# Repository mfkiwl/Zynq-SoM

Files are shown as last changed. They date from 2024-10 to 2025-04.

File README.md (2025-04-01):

# Zynq SoM Board

## Overview
This repository contains the hardware design files for a System on Module based on Xilinx Zynq 7020 SoC (FPGA + Dual Core ARM Cortex A9).

<!-- ![](img/zynq_pcb_render_test.png) -->
<!-- ![](img/pcb2blender_test_dark.png) -->
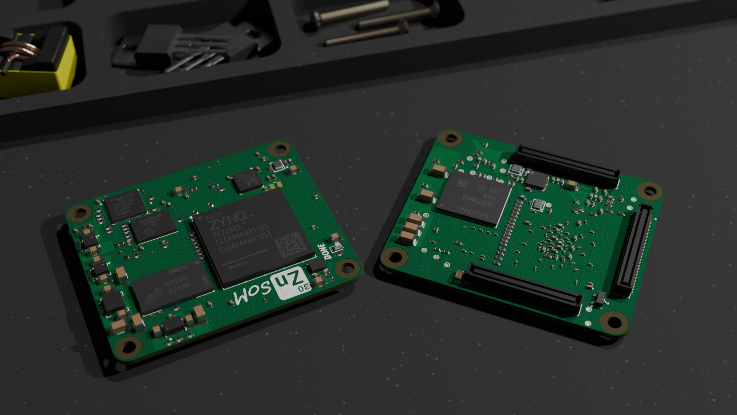
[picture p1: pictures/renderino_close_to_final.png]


## Description

> [!Warning] 
> First prototype is under testing. The design has not been fully verified.

#### Block Diagram

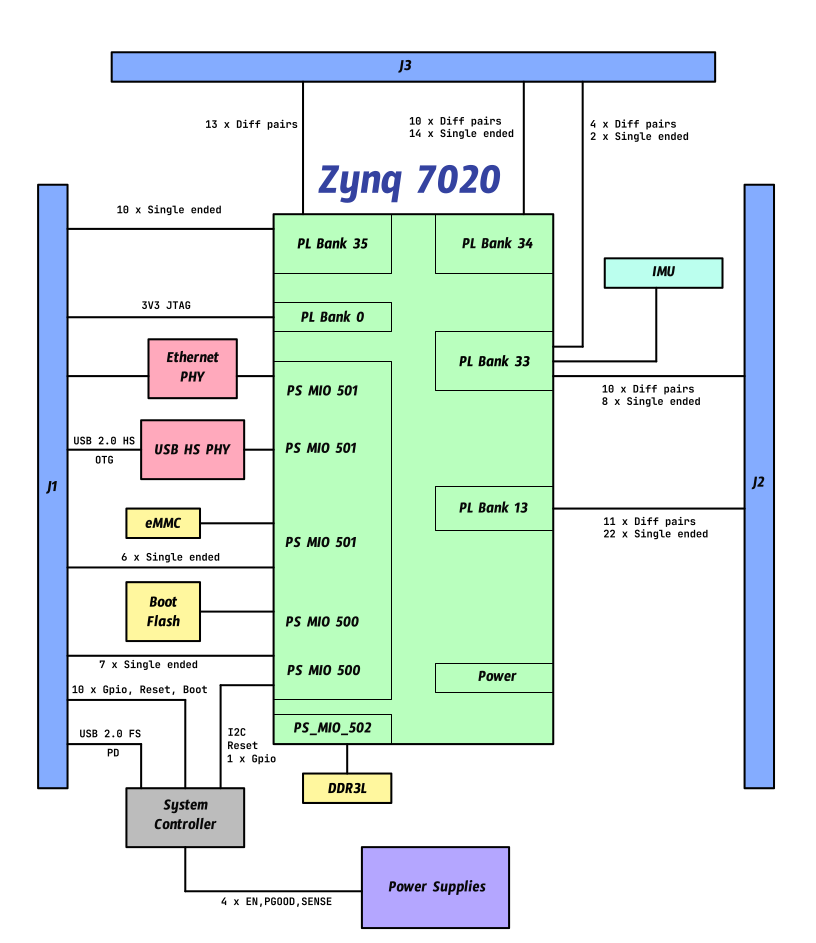
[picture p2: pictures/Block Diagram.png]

##  Features

Memory

- 512Mb DDR3L RAM
- 8Gb eMMC
- 16Mb Boot Flash

Connectivity

- 1x **Ethernet Gigabit**
- 1x **USB 2.0 High Speed** OTG 
- 1x **USB 2.0 Full speed** + USB PD (STM32)

- 7x Zynq PS GPIO (3.3V)
- 6x Zynq PS GPIO (1.8V) (External SD Card)
- 48x Zynq PL differential pairs (1.2-3.3V)
- 56x Zynq PL single ended IO (1.2-3.3V)
- 8x STM32 GPIO (3.3V)

Debug

- Zynq JTAG (3.3V)
- STM32 SWD (3.3V)

## Folder Structure

The repository is structured as follows:
- `schematics` contains the Kicad schematic sheets and schematic pdf 
- `scripts` contains a collection of python scripts used during the SoM/Carrier design phase
- `manufacturing/assembly` containts the BOM and pick-and-place position files
- `manufacturing/fabrication` containts the Gerber files and fabrication pdf 
- `lib` contains footprints and 3d models

## Production

JLCPCB ordering information:

- Layers: 8
- PCB Thickness: 1.2 mm
- Material Type: FR-4 TG155
- Stackup:  JLC08121H-1080A
- Outer Copper Weigth:  1 oz
- Inner Copper Weigth: 0.5 oz
- Minimum via diameter/hole-size: 0.3/0.2 mm
- Via Covering: Epoxy Filled and Capped
- Surface finish: ENIG

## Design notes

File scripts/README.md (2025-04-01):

# Scripts

This  folder contains:
- A python script to add die lengths to the Xilinx SoC footprint
- A python script to calculate SoM pcb track propagation delays
- A Kicad plugin to create a carrier pcb template
- A bash script to generate carrier connector symbols

## Requirements
python pandas

## `footprint_add_die_lengths.py`

This script adds die lengths to the Zynq SoC `<footprint_name>.kicad_mod` footprint.

Xilinx provides Die-to-Package delay data by specifying **max** and **min** delay values (in *ps*). Unluckly, Kicad footprints can only store die-length values (in *mm*).

Equivalent Die-length values are calculated as the average Die-to-Package delay multiplied by the microstrip propagation speed (approximated to 1/6 *mm/ps* for common FR4 boards).

$$ \frac{T_{D,max} + T_{D,min}}{2}\cdot V_{p*}$$

Where:
- $V_{p*}$ = miscrostrip propagation speed (hardcoded to 1/6 *mm/ps*)
- $T_{D}$ = Die-to-Package delay (*ps*)

### Usage
Run in terminal 
```bash
python footprint_add_die_lengths.py xc7z020clg484_delays.csv CLG484_XIL.kicad_mod
```
The resulting footprint is saved as `<footprint_name>_with_die_lengths.kicad_mod`

## `calculate_track_delays.py`
This script calculates propagation delays/skews for the following signal groups:
- DDR CMD/ADDR Bus
- DDR Data lanes
- Boot flash QSPI 
- eMMC SDIO 
- ETH RMGII TX
- ETH RMGII RX
- USB ULPI

Delays are calculated as 

$$ \frac{DL}{V_{p*}} + \sum_{layers} \frac{TL_{\,layer}}{V_{p,layer}}$$

Where:
- $DL$ = Package Die-Length [*mm*] (stored in footprint)
- $V_{p*}$ = 1/6 *mm/ps* (used during Die-Length calculation see [footprint_add_die_lengths](#footprint_add_die_lengthspy))
- $TL_{\,layer}$ = signal trace length for that specific layer [*mm*]
- $V_{p,layer}$ = signal propagation speed for that specific layer and signal type (differential or single-ended) [*mm/ps*]

>[!NOTE]
>- Outer layer Propagation speeds (microstrip) are lower compared to inner layers (stripline).
>- Propagation speed can vary between differential and single-ended signals

Via delays are not considered in the calculations. 

### Usage
1. With pcbnew create a Net Inspector Report named `tracklengths.csv` and save it inside `/scripts` subfolder
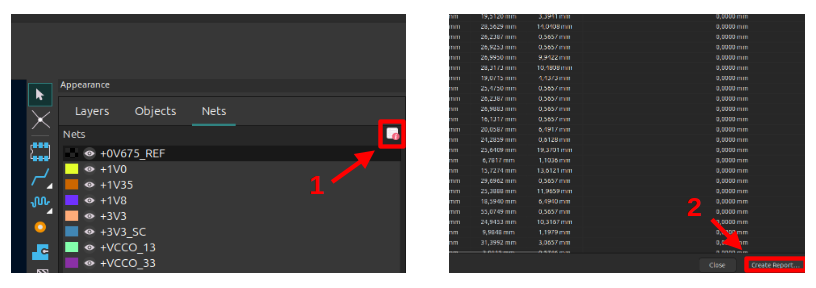
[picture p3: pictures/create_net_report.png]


2. Run in terminal:
```bash
python calculate_track_delays.py tracklengths.csv
```
Results are printed out in terminal.

## `create_carrier_template_plugin.py` 

This script generates a `.kicad_pcb` template used as a starting point for carrier board designs.

It places footprints for
- mating connectors (with die-lengths*)
- standoffs
- testing probes

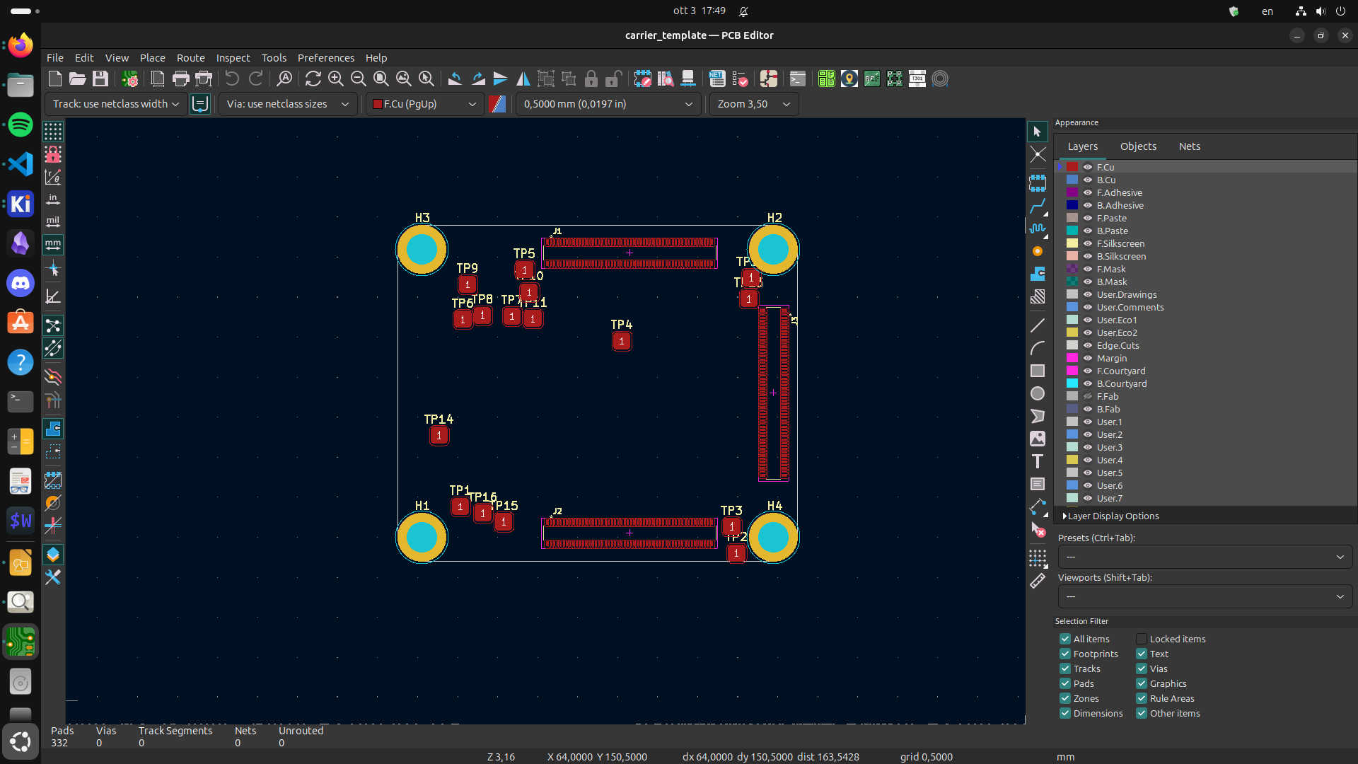
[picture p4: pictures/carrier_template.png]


### Usage
This script needs to be executed inside pcbnew Python scripting console by running:
```python
import os
exec(open(os.path.expandvars("${KIPRJMOD}/scripts/create_carrier_template_plugin.py")).read())
```
The `.kicad_pcb` template file can be found inside the `carrier_template` folder, together with the `.csv` files that will be used by [symbol_creation.bash](#symbol_creationbash) to create the SoM carrier connector symbols.

>[!NOTE]
>Schematic symbols need to be manually linked to the  generated footprints:
>- symbol references needs to be edited to match the  respective `.kicad_pcb` footprint references
>- symbol footprints needs to match the `.kicad_pcb` footprints
## `symbol_creation.bash`

This bash script uses the previously generated `.csv` files to create a  symbol library (`.lib`) containing the SoM carrier  connector symbols.
### Usage
Run in terminal:
```bash
source symbol_creation.bash
```
The library file is saved as `symbol_Zynq_SoM.lib` (Kicad < V6.0). Conversion to the newer `.kicad_sym` format can be done during import by clicking the "Migrate Library" button inside Symbol Library Manager.

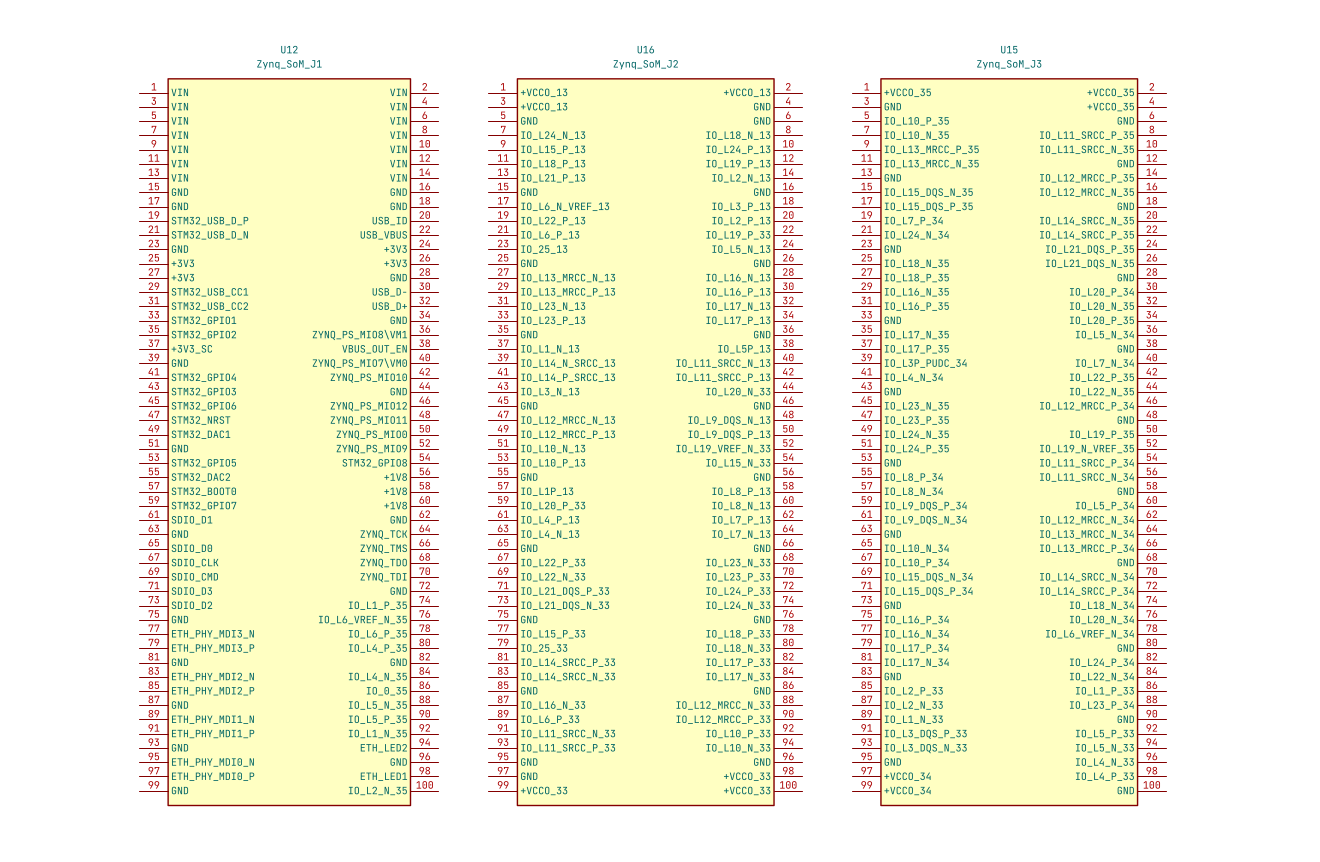
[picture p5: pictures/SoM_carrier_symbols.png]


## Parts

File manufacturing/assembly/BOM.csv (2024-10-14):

Reference | Value | Footprint | Qty | LCSC Part | Digikey
C1,C7,C8,C9,C10,C11,C12,C15,C32,C34,C36,C38,C40,C44,C45,C52,C57,C59,C66,C70,C71,C77,C78,C79,C87,C88,C95,C97,C103,C123,C128,C129,C139,C141 | 4u7 | Capacitor_SMD:C_0402_1005Metric | 34 | C368809
C2,C3,C4,C5,C6,C16,C17,C18,C19,C20,C21,C22,C138,C142 | 100n | Capacitor_SMD:C_0402_1005Metric | 14 | gia
C13,C23,C33,C35,C37,C39,C41,C43,C46,C47,C48,C50,C53,C54,C55,C56,C61,C62,C67,C69,C72,C76,C80,C81,C82,C83,C84,C85,C89,C90,C91,C92,C94,C98,C99,C100,C101,C102,C107,C108,C112,C114,C130,C131,C132,C133,C134,C135,C136,C137 | 470n | Capacitor_SMD:C_0201_0603Metric | 50 | C85926
C14 | 100n | Capacitor_SMD:C_0402_1005Metric | 1 | -
C24,C27,C28,C29,C31,C49,C73,C74,C75,C86,C127 | 47u | Capacitor_SMD:C_0805_2012Metric | 11 | C16780
C25,C26,C30 | 22u | Capacitor_SMD:C_0805_2012Metric | 3 | C98190
C42,C51,C58,C60,C63,C64,C68,C93,C96 | 100u | Capacitor_SMD:C_1206_3216Metric | 9 | C15008
C65 | 10u | Capacitor_SMD:C_0402_1005Metric | 1 | C15525////
C104,C105,C106,C109,C110,C111,C113,C118,C119,C120,C121,C122,C124,C125,C126 | 47n | Capacitor_SMD:C_0201_0603Metric | 15 | C85925
D2 | LED_Small | LED_SMD:LED_0603_1608Metric | 1 | -
H1,H2,H3,H4 | MountingHole | Mylibrary:MountingHole_2.7mm_M2.5_ISO14580_MOD | 4 | -
J1,J2,J3 | DF40C-100DS-0.4V_51 | Mylibrary:HRS_DF40C-100DS-0.4V_51_ | 3 |  | DF40HC(3.0)-100DS-0.4V(51)
L1 | 3u3 | Mylibrary:L_0806_2.0x1.6mm | 1 | C98336
L2,L3,L4,L6,L7,L8,L9 | 120R | Inductor_SMD:L_0402_1005Metric | 7 | C275478
L5 | 600@100MHz | Inductor_SMD:L_0402_1005Metric | 1 | C337875/gia
Q3 | NMOS | Package_TO_SOT_SMD:SOT-23 | 1
R1,R5,R6,R13,R15,R39,R40,R41,R42,R43,R44,R74,R75,R76,R77,R86,R87,R88,R89,R90,R92,R93,R94,R97,R100 | 10k | Resistor_SMD:R_0402_1005Metric | 25 | C25744/gia
R2,R20,R21,R22,R49,R51,R52,R53,R54,R55,R56,R57,R58,R59,R60,R61,R62,R63,R64,R65,R66,R67,R68,R69,R70,R71,R72,R73,R95,R96 | 22R | Resistor_SMD:R_0402_1005Metric | 30 | C114765/C25105
R3,R4,R14 | 1k5 | Resistor_SMD:R_0402_1005Metric | 3 | C25867
R7,R8,R9,R10,R11,R12,R17,R18,R19,R48,R98,R99 | 4k7 | Resistor_SMD:R_0402_1005Metric | 12 | C25940
R16 | 2k49 | Resistor_SMD:R_0402_1005Metric | 1 | C25884
R23,R27,R28,R29,R30,R31,R32,R35,R36,R78,R79,R80,R81,R82,R83,R84,R85 | 100k | Resistor_SMD:R_0402_1005Metric | 17 | C60491
R24 | 8k06 | Resistor_SMD:R_0402_1005Metric | 1 | C25923
R25 | 28k7 | Resistor_SMD:R_0402_1005Metric | 1 | C26972
R26,R33,R37 | 200k | Resistor_SMD:R_0402_1005Metric | 3 | C137903
R34 | 44k2 | Resistor_SMD:R_0402_1005Metric | 1 | C25895
R38 | 160k | Resistor_SMD:R_0402_1005Metric | 1 | C25757
R45 | 240R | Resistor_SMD:R_0402_1005Metric | 1 | C25094
R46,R47,R50 | 100R | -- mixed values -- | 3 | -- mixed values --
R91 | 330 | Resistor_SMD:R_0402_1005Metric | 1
TP1,TP2,TP3,TP4,TP5,TP6,TP7,TP8,TP9,TP10,TP11,TP12,TP13,TP14,TP15,TP16 | TestPoint | Mylibrary:TestPoint_Pad_D0.7mm | 16 | -
U1 | MT41K256M16TW-107_P | Mylibrary:BGA96C80P9X16_1400X800X120 | 1 | gia
U2 | XC7Z020-CLG484 | Mylibrary:CLG484_XIL-L_new | 1 | gia
U3 | RTL8211F | Mylibrary:RTL8211F-CG_RTK-L | 1 | C187932
U4,U6 | MPM3834 | Mylibrary:MPM3834 | 2 |  | MPM3834CGPA-Z
U5 | USB3318 | Package_DFN_QFN:QFN-24-1EP_4x4mm_P0.5mm_EP2.6x2.6mm | 1 |  | USB3318C-CP-TR
U7 | IS21ES08G | Mylibrary:BGA153N50P14X14_1150X1300X100 | 1 |  | IS21ES08GA-JCLI-TR
U8 | TPSM82864 | Mylibrary:B0QFN_RDJ | 1 | C5219321
U9 | STM32G431CBUx | Mylibrary:STM32G431CBU6 | 1 | gia
U10 | MPM3822 | Mylibrary:QFN_2p5x3p5x1p6_MNP | 1 | C5799652
U11 | W25Q128JVS | Package_SON:WSON-8-1EP_8x6mm_P1.27mm_EP3.4x4.3mm | 1 | C401662
U13 | TPS7A20 | Mylibrary:TLV707 | 1 | gia
U14 | BMI323 | Mylibrary:BMI323_BOS | 1 | C5368700
X1 | ASCO | Mylibrary:Oscillator_SMD_Kyocera_4PIN_2.0x1.6mm | 1 |  | KC2016Z13.0000C1KX00
X2 | ASE-xxxMHz | Mylibrary:Oscillator_SMD_Kyocera_4PIN_2.0x1.6mm | 1 |  | KC2016Z25.0000C1KX00
X3 | CMOS_OSC | Mylibrary:Oscillator_SMD_Kyocera_4PIN_2.0x1.6mm | 1 |  | KC2016Z33.0000C1KX00

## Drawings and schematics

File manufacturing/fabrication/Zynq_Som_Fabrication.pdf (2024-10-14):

## Layer Stack Legend

# Layer 0.0764 mm

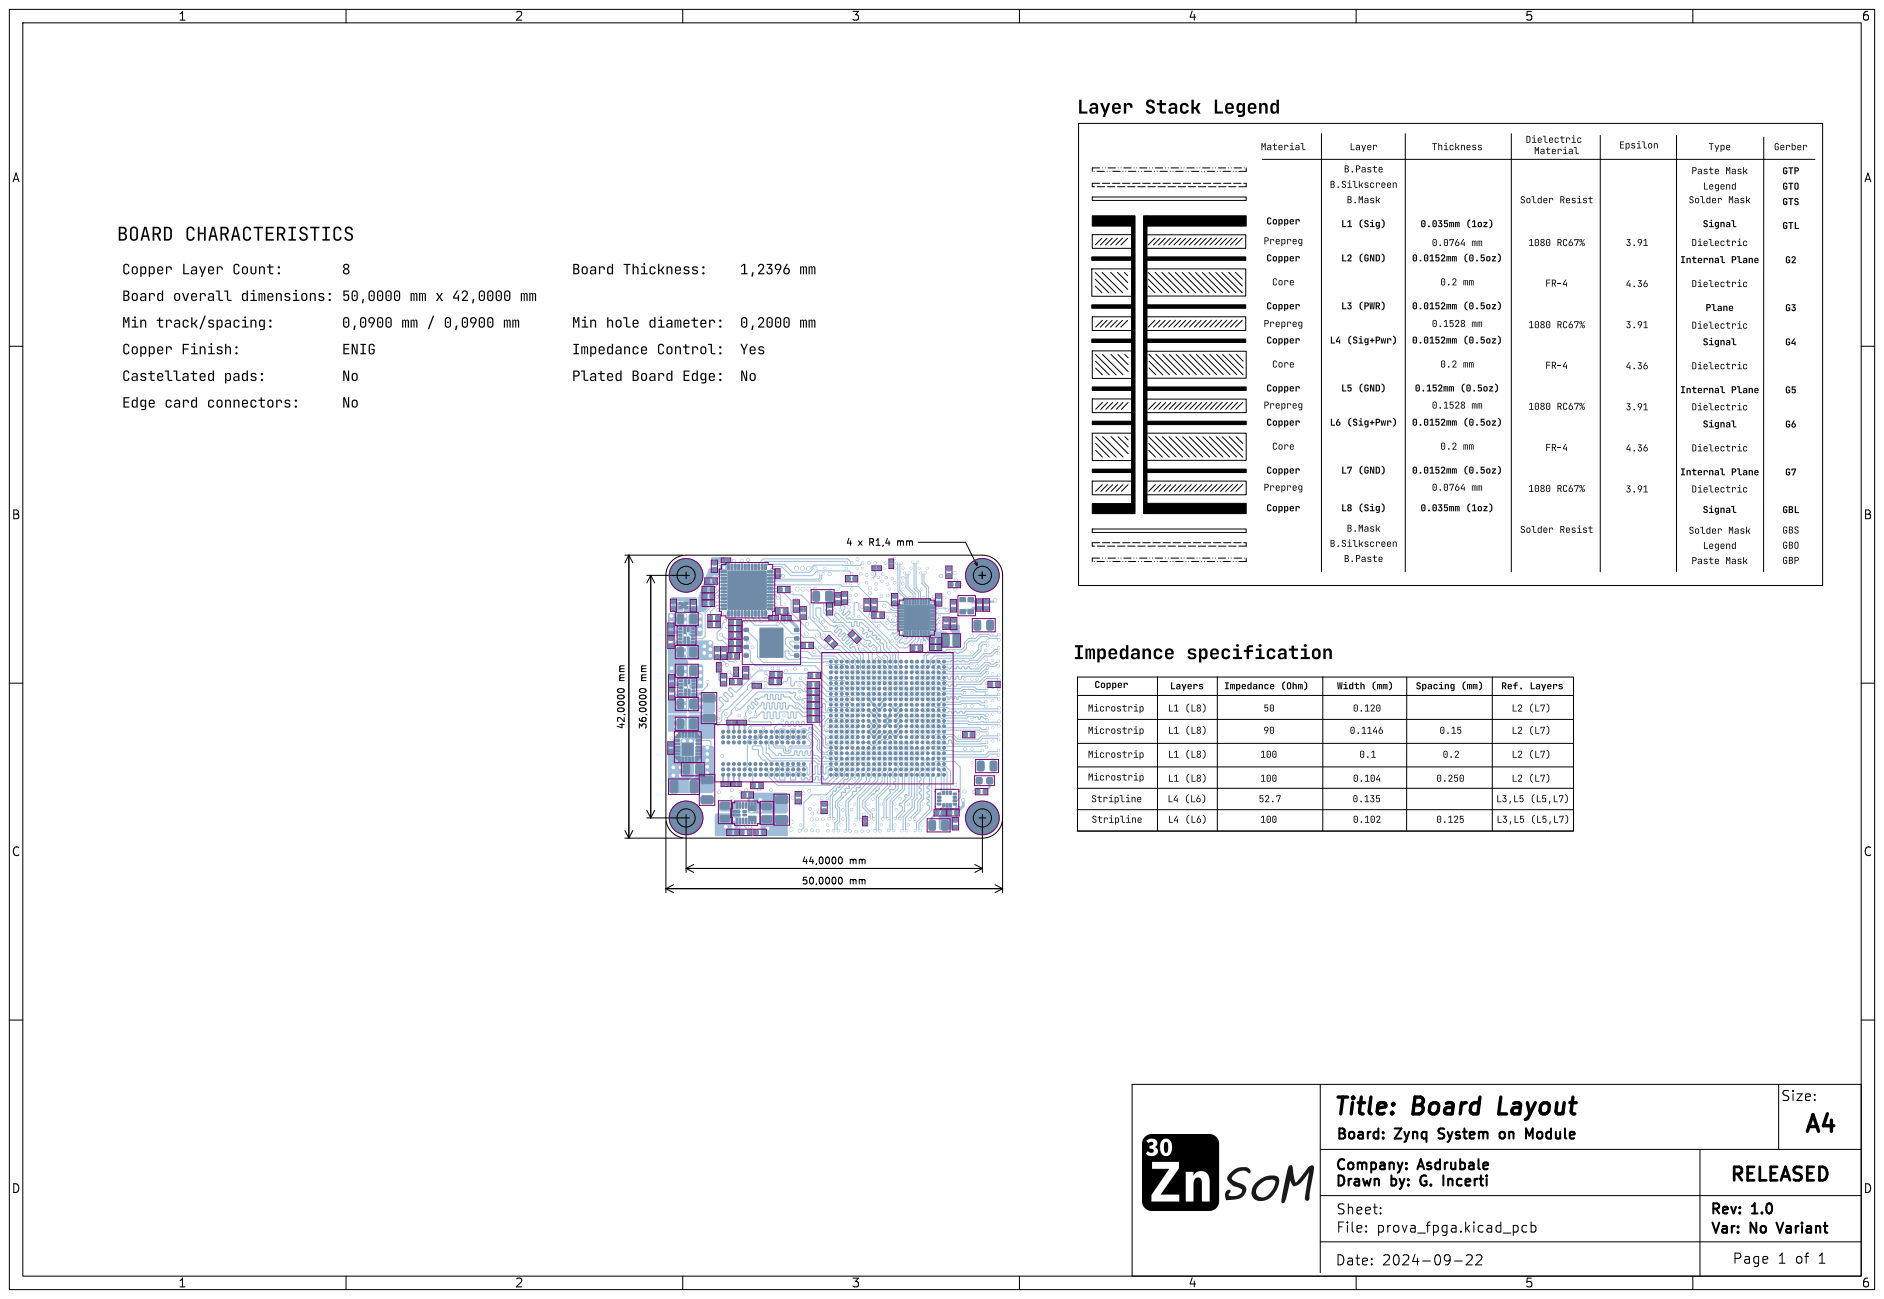
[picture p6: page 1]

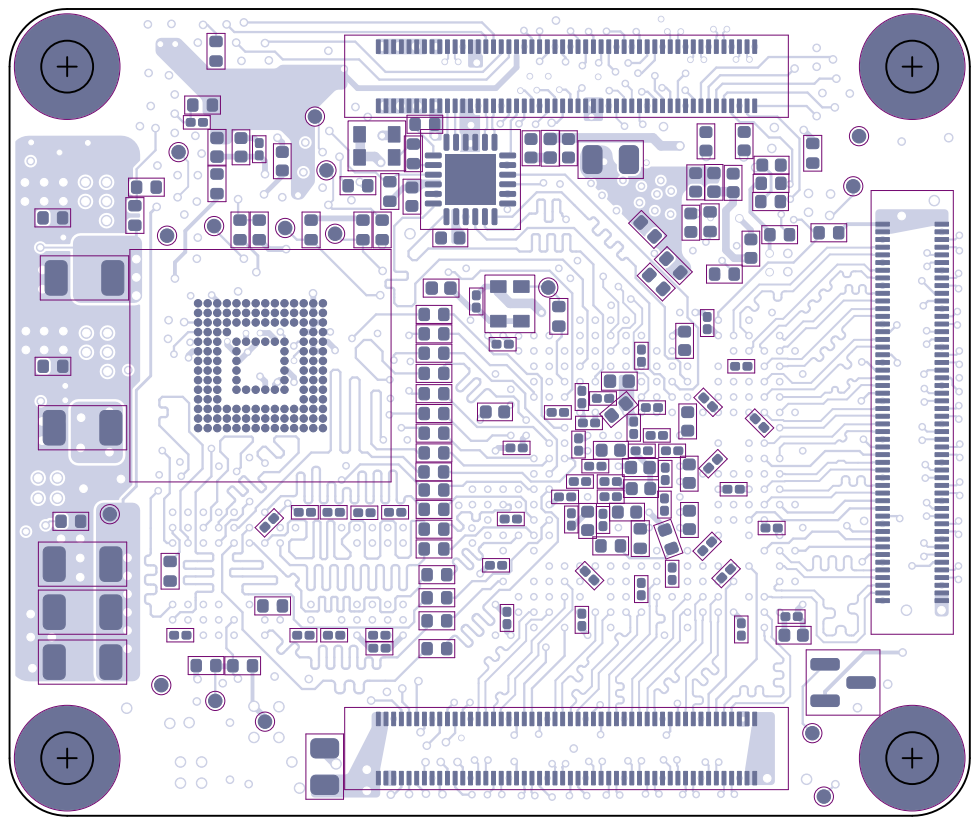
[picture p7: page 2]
D Date: 2024-09-22; Rev: 1.0 Size: Page 1 of 1 Title: Board Layout File: prova_fpga.kicad_pcb Sheet: Company: Asdrubale; Drawn; by: G. Incerti; Var: No Variant Board: Zynq System on Module; RELEASED

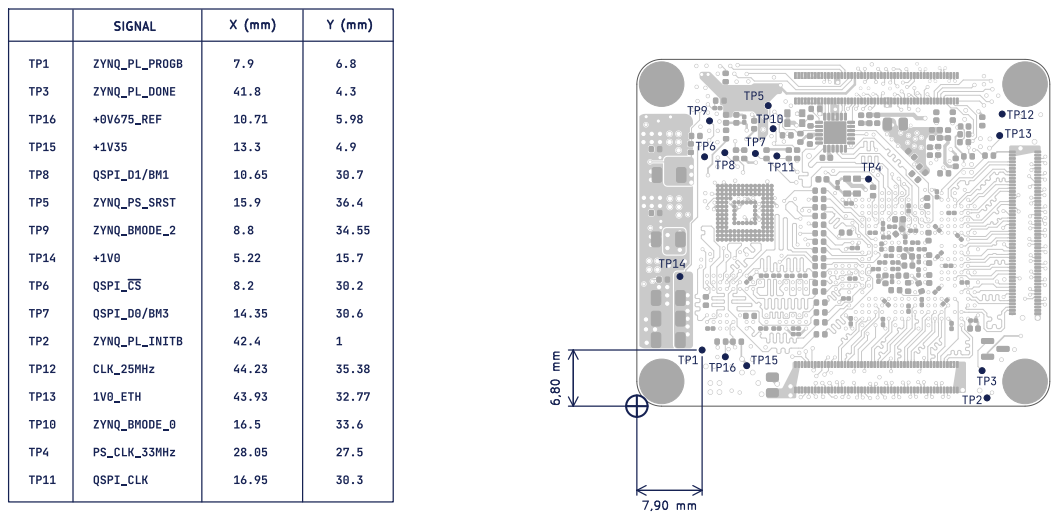
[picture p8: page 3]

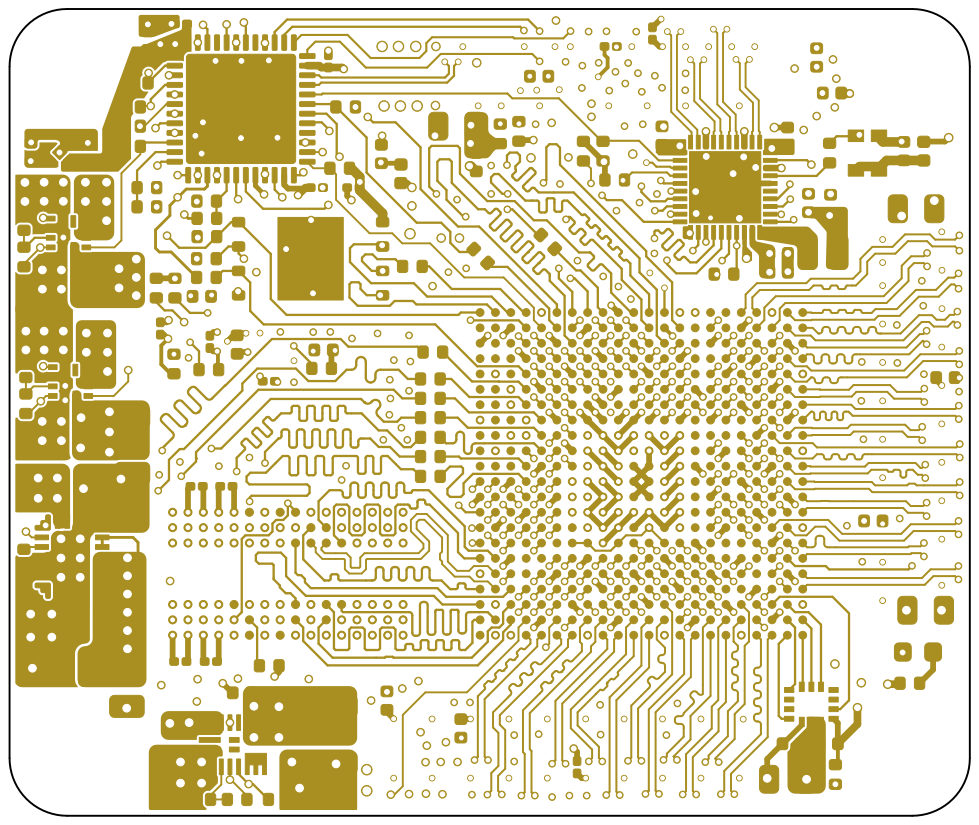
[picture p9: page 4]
D Date: 2024-09-22; Rev:; Size: Page 1 of; 1 Title: Board Layout File: prova_fpga.kicad_pcb Sheet: Company: Asdrubale; Drawn; by: G. Incerti; Var:; No Variant Board:; Zynq System on; Module; RELEASED

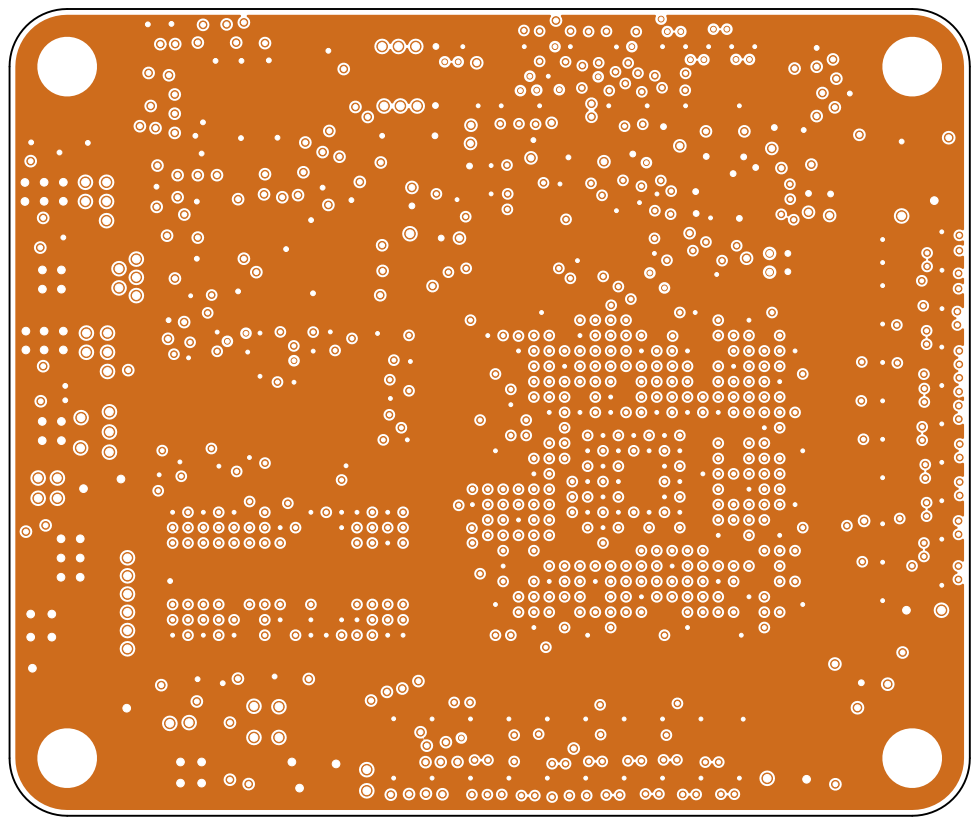
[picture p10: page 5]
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

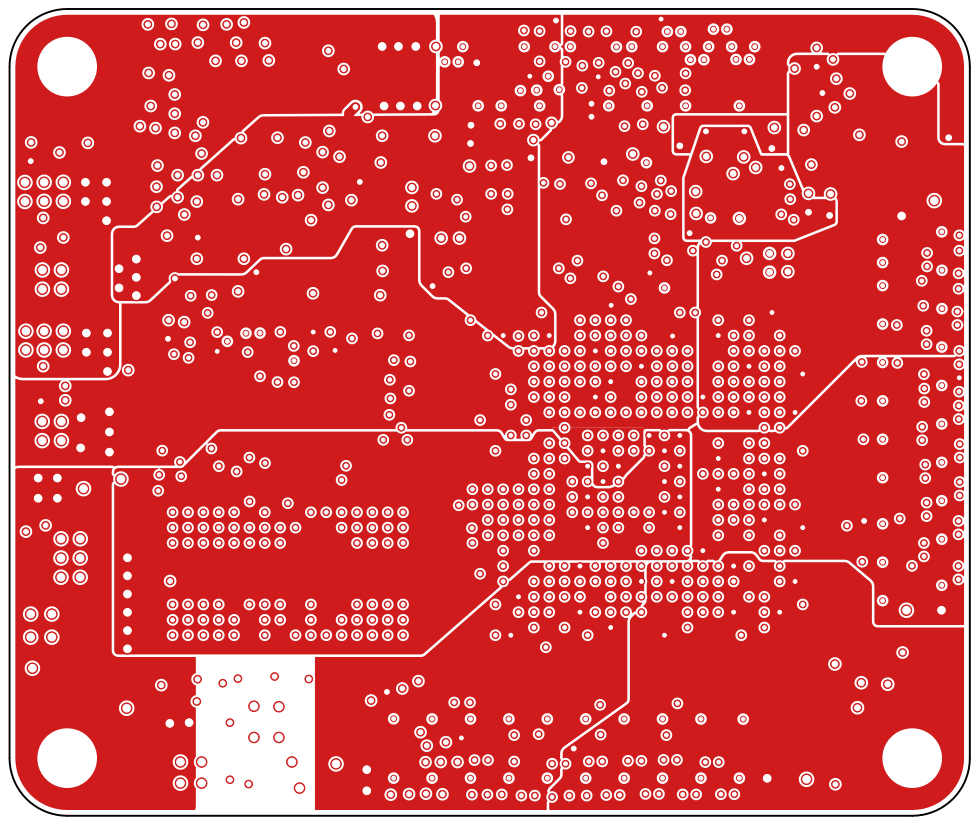
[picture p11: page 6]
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

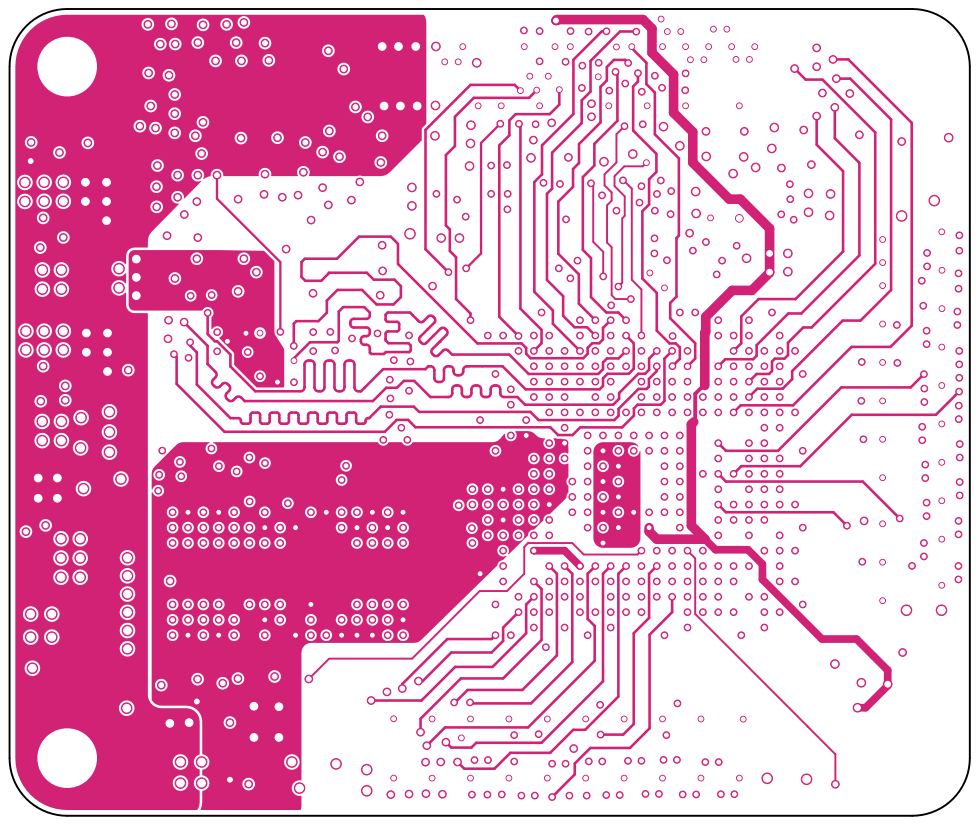
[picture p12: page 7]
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

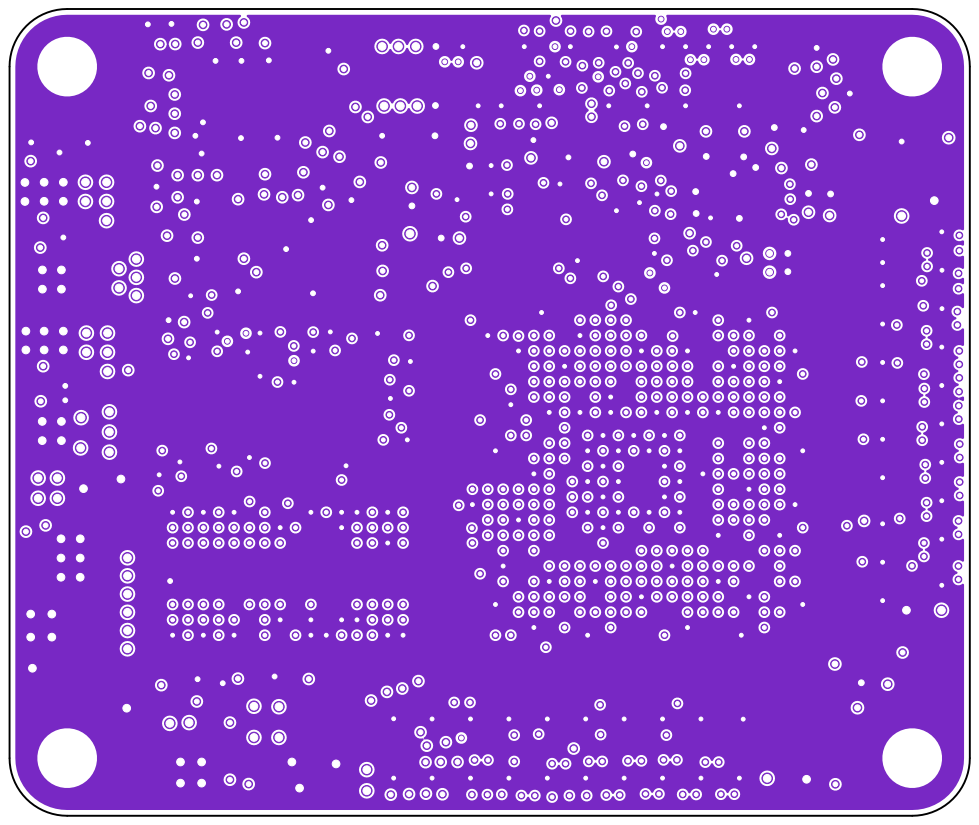
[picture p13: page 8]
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

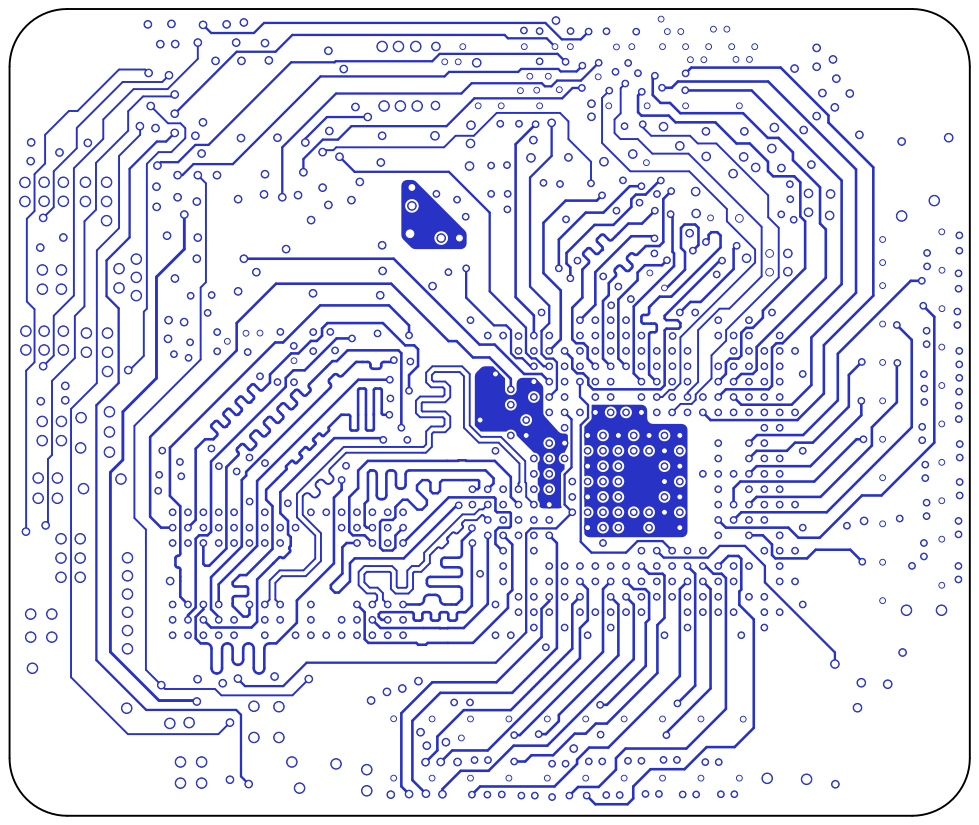
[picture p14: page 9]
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

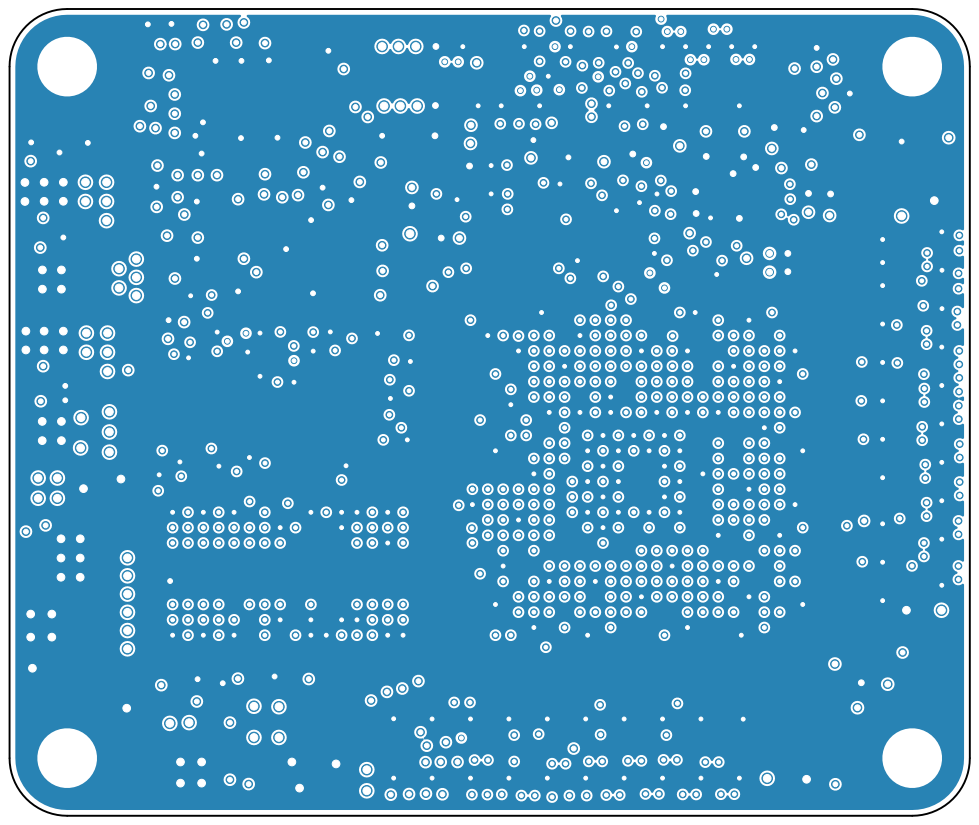
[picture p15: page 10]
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

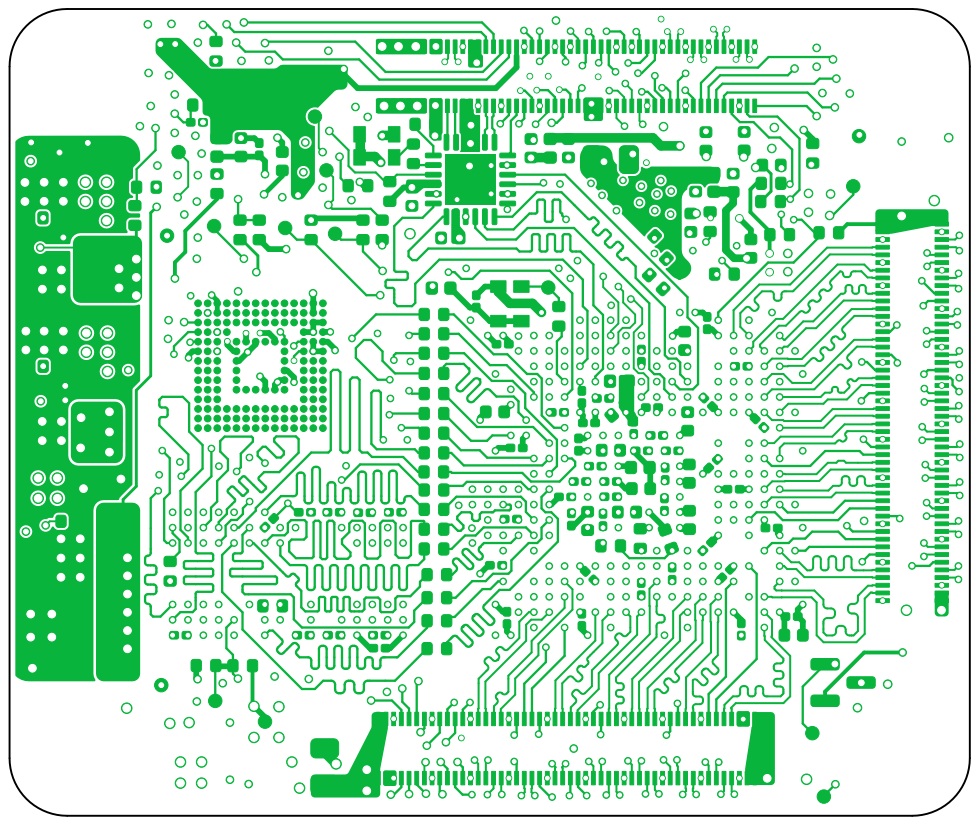
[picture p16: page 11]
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

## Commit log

2024-10-15 fix: fix python scripts
    [carrier_template.kicad_pcb, symbol_J1.csv]
2024-10-15 fix: add footprints for carrier creation
2024-10-22 docs: clean up fabrication docs
    [Zynq_SoM_Testpoints.csv]
2024-10-22 refactor: add <footprint_name>.kicad_mod as input parameter for footprint_add_die_lengths.py
2025-04-01 chore: upgrade to Kicad 9.0
    [DDR3L.kicad_sch, Ethernet PHY.kicad_sch, Power.kicad_sch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]
